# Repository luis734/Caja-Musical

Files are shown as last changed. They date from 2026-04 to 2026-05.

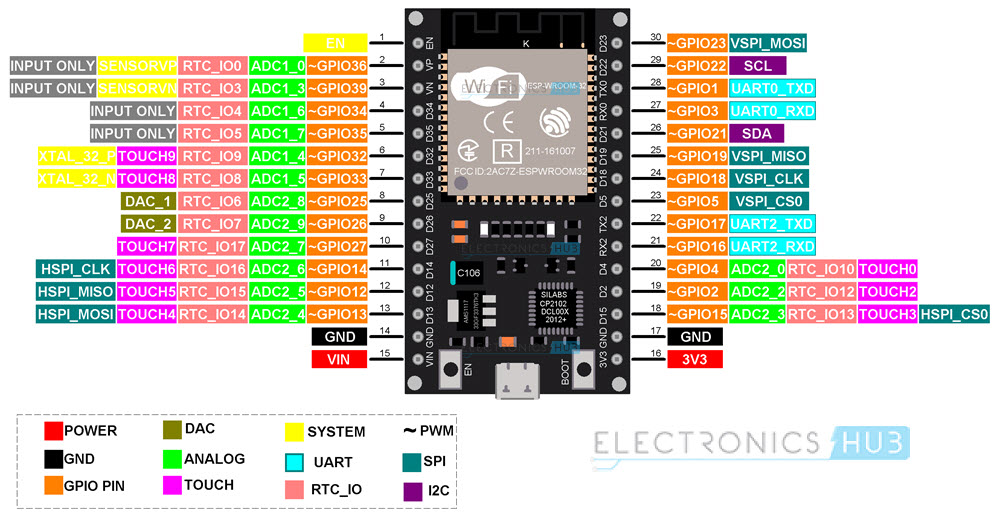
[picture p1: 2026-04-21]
docs/conexiones/ESP32-Pinout.jpg

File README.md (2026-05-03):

# 🎵 Caja Musical RFID — Tocadiscos Interactivo

Una caja musical tipo tocadiscos construida con **ESP8266 + RFID + DFPlayer Mini**, donde al acercar una tarjeta RFID al lector se reproduce automáticamente una canción almacenada en una MicroSD.

La idea principal es simular la experiencia de colocar un vinilo sobre un tocadiscos:

➡️ Acercas una tarjeta RFID  
➡️ Comienza a reproducirse la música  
➡️ Al retirar la tarjeta, la música se detiene

Actualmente el proyecto funciona sobre protoboard y está pensado como un proyecto personal realizado por gusto, con posibilidad de seguir creciendo hacia una versión física más elaborada con disco giratorio y mejor acabado visual.

---

# ✨ Características

- Reproducción automática de música mediante RFID
- Modo normal de uso (funcionamiento principal)
- Modo administrador para programar tarjetas
- Soporte para tarjetas **MIFARE Ultralight**
- Uso de **DFPlayer Mini + bocina 3W**
- LED RGB con efecto de respiración (opcional)
- Proyecto modular y fácil de expandir

> El LED RGB es únicamente decorativo y puede eliminarse fácilmente sin afectar el funcionamiento principal.

---

# ⏯️ Comportamiento en tiempo real

### Tarjeta presente

▶️ La música se reproduce continuamente

### Tarjeta retirada

⏹️ La música se detiene

---

# 🧩 Componentes Utilizados

- ESP32
- RC522 RFID Reader
- DFPlayer Mini
- Bocina de 3W
- LED RGB (opcional)
- MicroSD
- Tarjetas RFID MIFARE Ultralight
- Protoboard
- Cables Dupont

---

# 🔌 Diagramas de Conexión

Dentro de:

```text
/docs/conexiones
```

se incluyen:

- Diagramas de conexión individuales
- Diagrama completo del sistema
- Archivos fuente de Fritzing
- Listado de conexiones para una visualización mas sencilla

> [!NOTE]  
> Actualmente solo se realizó el diagrama de conexiones sobre protoboard.  
> Aun no se realizó diseño para PCB o placa de impresión.

---

# 📄 Documentación

Si necesitas saber como funciona algo mas especificamente puede revisar dentro de:

```text
/docs
```

En la raíz de esta carpeta encontrarás, información importante tipo:

- ¿Cómo funciona el Modo Admin? (`modo_admin.md`)
- ¿Cómo vincular las canciónes de la Micro SD y las RFID Tags? (`rfid_canciones.md`)
- ¿Cómo solucionar errores comúnes que te puedas encontrar? (`problemas_comunes.md`)

---

# 📁 Estructura  del Proyecto

```text
├── docs/
|   └── documentación_características.md
│   └── conexiones/
│       ├── diagramas individuales
│       ├── diagrama completo
│       ├── archivos Fritzing
│       └── listado de conexiones
│
├── src/
│   └── código fuente para ESP32
│
└── README.md
```

---

# 📌 Nota Final

Este proyecto nació como algo personal y experimental, pero está pensado para seguir creciendo hasta convertirse en una verdadera caja musical estilo tocadiscos interactivo.

Mas que solo reproducir música, la idea es crear una experiencia física y visual alrededor de ella.

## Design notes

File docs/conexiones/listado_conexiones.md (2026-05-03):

# 🔌 Conexiones del Proyecto

Este documento describe las conexiones físicas entre los módulos utilizados en la Caja Musical RFID.

El sistema principal está compuesto por:

- ESP32
- RC522 RFID Reader
- DFPlayer Mini
- Bocina de 3W
- LED RGB (opcional)

Actualmente todo el sistema está montado sobre **protoboard**, sin PCB personalizada.

---

# 📍 Protocolos de Comunicación Utilizados

| Módulo | Protocolo |
| --- | --- |
| RC522 | SPI |
| DFPlayer Mini | Serial UART (SoftwareSerial) |
| LED RGB | GPIO PWM |
| Bocina | Salida directa del DFPlayer  |

---

# 🧠 Consideraciones Importantes

## Niveles de Voltaje

El **RC522 trabaja a 3.3V**, por lo que debe conectarse correctamente para evitar daños.

El **DFPlayer Mini suele trabajar a 5V**, aunque puede funcionar con algunas configuraciones a menor voltaje.

## RX del DFPlayer

Se recomienda usar un pequeño divisor de voltaje en el pin **RX del DFPlayer Mini**, especialmente si se conecta desde una salida de 5V.

Esto ayuda a proteger el módulo.

## Alimentación

La bocina de 3W puede demandar más corriente de la esperada.

Si el audio presenta fallos o reinicios, se recomienda usar una fuente externa estable.

---

# 🔗 ESP32 ↔ RC522 (SPI)

> [!WARNING]
> No conectar el RC522 a 5V.

| ESP32 | RC522 |
| --- | --- |
| D5 | SDA / SS |
| D18 | SCK |
| D23 | MOSI |
| D19 | MISO |
| D22 | RST |
| 3.3V | 3.3V |
| GND | GND |

---

# 🎵 ESP32 ↔ DFPlayer Mini

| ESP32 | DFPlayer Mini |
| --- | --- |
| TX2 | RX |
| RX2 | TX |
| VIN | VCC |
| GND | GND |

> [!NOTE]
> Verifica los pines reales usados en tu código fuente, especialmente si cambias SoftwareSerial.

---

# 🔊 DFPlayer Mini ↔ Bocina 3W

| DFPlayer Mini | Bocina |
| --- | --- |
| SPK_1+ | Cable rojo |
| SPK_2- | Cable negro|

> [!NOTE]
> No conectar la bocina a GND.  
> Debe ir directamente entre SPK_1 y SPK_2.

---

# 🌈 ESP32↔ LED RGB (Opcional)

| ESP32 | LED RGB |
| --- | --- |
| D25 | R |
| D26 | G |
| D27 | B |
| GND | Cátodo común |

> [!NOTE]
> Debe haber una resistencia de entre 220 o 330 ohms entre el pin del ESP y cada pata del LED para evitar que se queme, para mas información revisa docs/conexiones/LedRGB.
> El LED RGB usa efecto de respiración decorativo y puede eliminarse fácilmente.

---

# 📋 Resumen de Pines Utilizados

| Pin ESP8266 | Uso |
| --- | --- |
| D17 (TX2) | DFPlayer RX |
| D16 (RX2) | DFPlayer TX |
| D22 | RC522 RST |
| D18 | RC522 SCK |
| D19 | RC522 MISO  |
| D23 | RC522 MOSI  |
| D5 | RC522 SDA |
| GPIO extra  | LED RGB |

---

# 🔄 Si usas otra placa (Arduino UNO / ESP8266 / etc.)

Debes revisar principalmente:

- Pines SPI
- Pines Serial
- Voltajes compatibles
- Capacidad de corriente
- Compatibilidad con SoftwareSerial

Puede requerir más cuidado con niveles de voltaje y memoria disponible.

---

# 📁 Diagramas Visuales

En esta misma carpeta encontrarás:

- Diagramas individuales
- Diagrama completo del sistema
- Archivos fuente de Fritzing

Estos diagramas sirven como referencia visual complementaria a esta tabla.

---

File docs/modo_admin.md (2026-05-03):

# ⚙️ Modo Administrador

Este es un modo especial para progrtamar nuevas tarjetas RFID.

## ¿Cómo entrara?

Hay una tarjeta predefinida como Tarjeta Master, su UID está hardcodeado en el código fuente en la variable global:

```text
adminUID
```

### Al acercar esta tarjeta:
➡️ El sistema entra en Modo Admin
### Al acercarla de nuevo:
⬅️ El sistema sale del Modo Admin

---

# ¿Cómo programar una tarjeta?

Estando en Modo Admin

### Paso 1

Acerca una tarjeta RFID MIFARE Ultralight (y mantenla sobre el lector)

### Paso 2

Desde el Monitor Serial, envía el número de canción desdeado
Ejemplo:

```text
12
```

### Paso 3

Ese valor se escribe en la memoria de la tarjeta RFID, ya puedes retirar la tarjeta del lector

Ahora al acercar esta tarjeta al lector reproducirá:

```text
012.mp3
```

> [!NOTE]
> Las Tags RFID solo reproducen la canción en modo normal.
> En modo admin siempre se intentaran reprogramar.

### Programar múltiples tarjetas

Puedes seguir acercando nuevas tarjetas y asignarles números de canciones una por una.

## 💡 Como hacer tu propia Tarjeta MASTER

Tienes que identificar cual es el UID de la Tarjeta que designaras como MASTER, desde el IDE de Arduino en la librería `MFRC522.h` puedes revisar ejemplos simples para:

- Leer los datos de la tarjeta
- Reprogramar UID de alguna tarjeta
- Entre otros ejemplos muy utiles.

De esta forma puedes ajustarte al UID definida o cambiarla por la que necesites.

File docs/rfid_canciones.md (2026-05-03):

# 💿 Funcionamiento: RFID ↔ Canciones

Este documento explica cómo se relacionan las **tarjetas RFID** con las canciones reproducidas en la **MicroSD** mediante el DFPlayer Mini.

La lógica del sistema es simple:

> 📀 Cada tarjeta RFID representa una canción

---

# 🧠 Idea General

1. Una tarjeta RFID guarda un número
2. El ESP8266 lee ese número
3. Envía ese número al DFPlayer Mini
4. El DFPlayer reproduce la canción correspondiente en la MicroSD

---

# 📡 Estructura de las Tarjetas RFID (MIFARE Ultralight)

Las tarjetas utilizadas son del tipo **MIFARE Ultralight**, que tienen una memoria organizada de la siguiente forma:

- 16 páginas (pages)
- Cada página tiene 4 bytes

## 📋 Distribución básica

| Página | Contenido |
|---|---|
| 0 - 3 | Información del fabricante (incluye UID) |
| 4 en adelante | Memoria libre para usuario |

---

## 🔑 UID de la tarjeta

Las primeras páginas contienen el identificador único (UID), que:

- Es de solo lectura
- Identifica cada tarjeta de forma única
- Se usa en el proyecto para definir la **tarjeta admin (master)**

---

# ✍️ Dónde se guarda la canción

El sistema escribe el número de canción en:

### 👉 Página 4 (quinta página)
Esto se hace en el **modo administrador**.

---

# ⚙️ ¿Qué se guarda exactamente?

Se guarda un número en formato texto, por ejemplo:

```text
5
```
ó
```text
12
```

Este número representa la canción que se va a reproducir.

---

# 🔄 Flujo completo

## 🔹Paso 1: Lectura de tarjeta

El RC522 detecta una tarjeta y el ESP32:
- Lee la página 4
- Obtiene el número almacenado

## 🔹Paso 2: Envío al DFPlayer

- El ESP32 envía ese número al DFPlayer Mini meidante
UART (Serial)

## 🔹Paso 3: Reproducción

- El DFPlayer Mini busca en la MicroSD el archivo correspondiente a ese número.

---

# 💾 Formato de las canciones en la MicroSD

Las canciones deben nombrarse con un formato especifico:

## 👉 3 dígitos con ceros a la izquierda

## 📀 Ejemplos
| Número en RFID | Archivo en MicroSD |
|---|---|
| 1 | 001.mp3 |
| 2 | 002.mp3 |
| 3 | 003.mp3 |
| 10 | 010.mp3 |
| 12 | 012.mp3 |

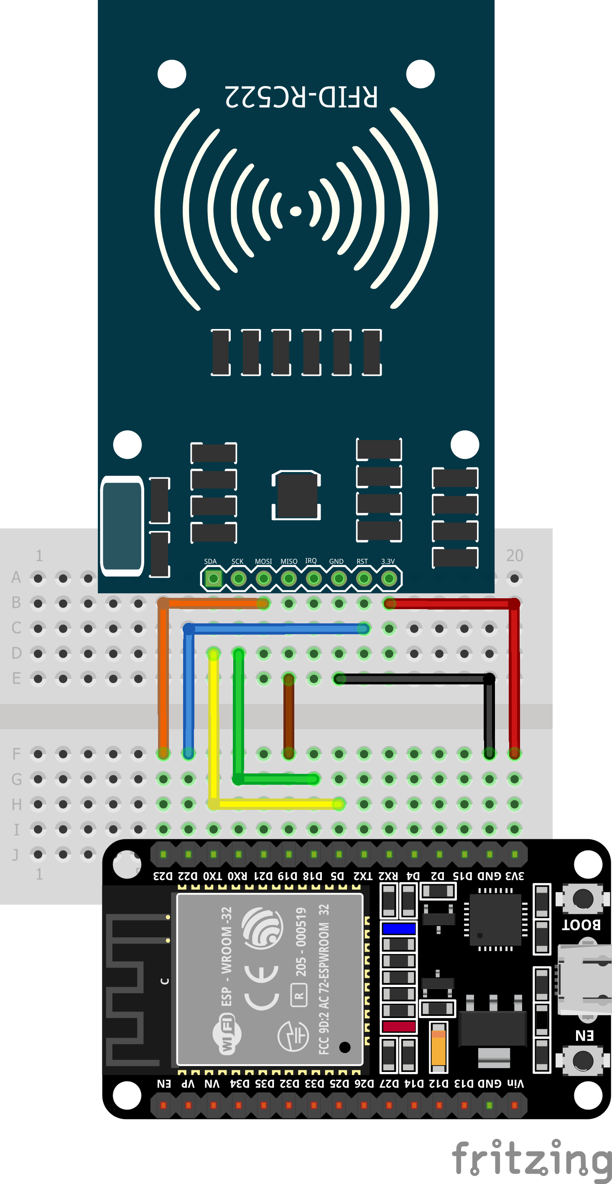
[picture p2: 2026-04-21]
docs/conexiones/RFID/RFID_v2.png

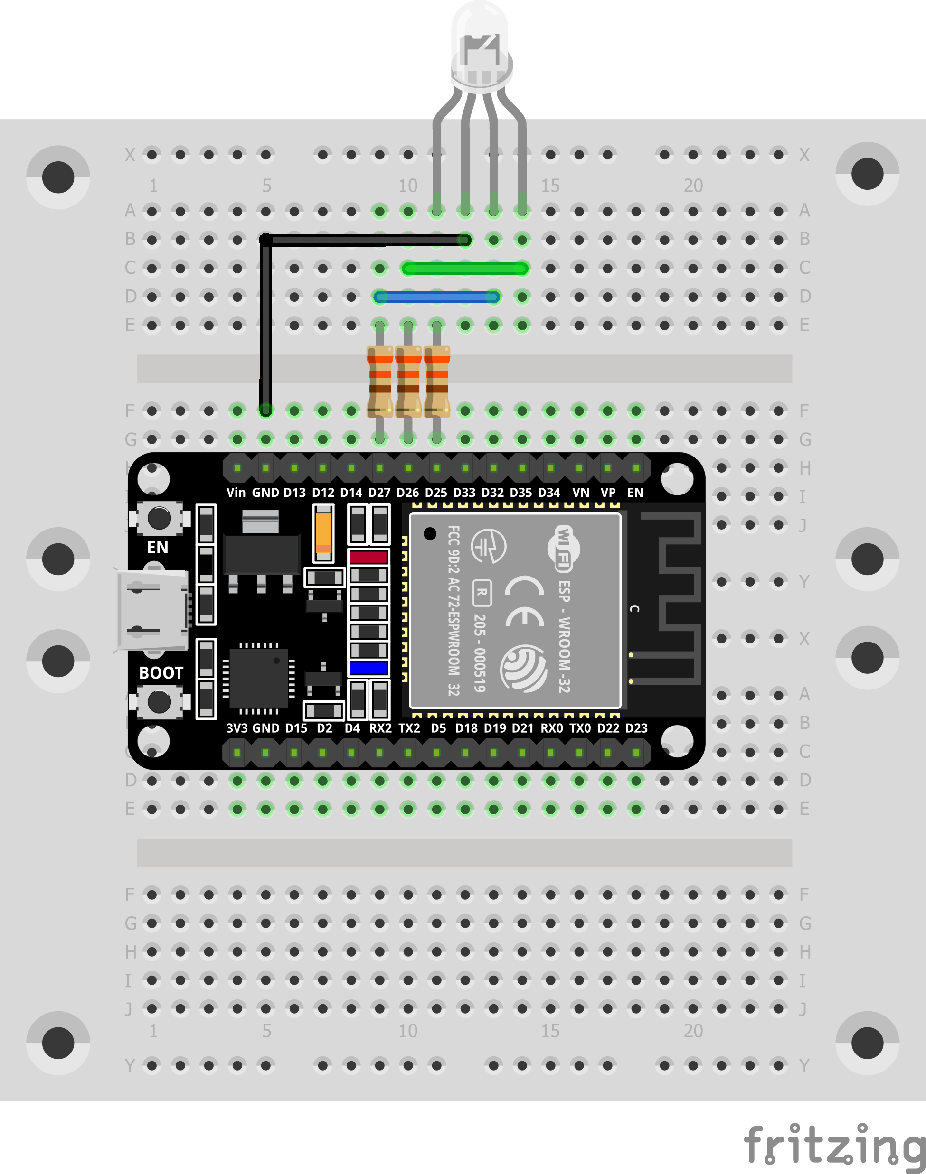
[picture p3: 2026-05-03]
docs/conexiones/RGB/RGB.png

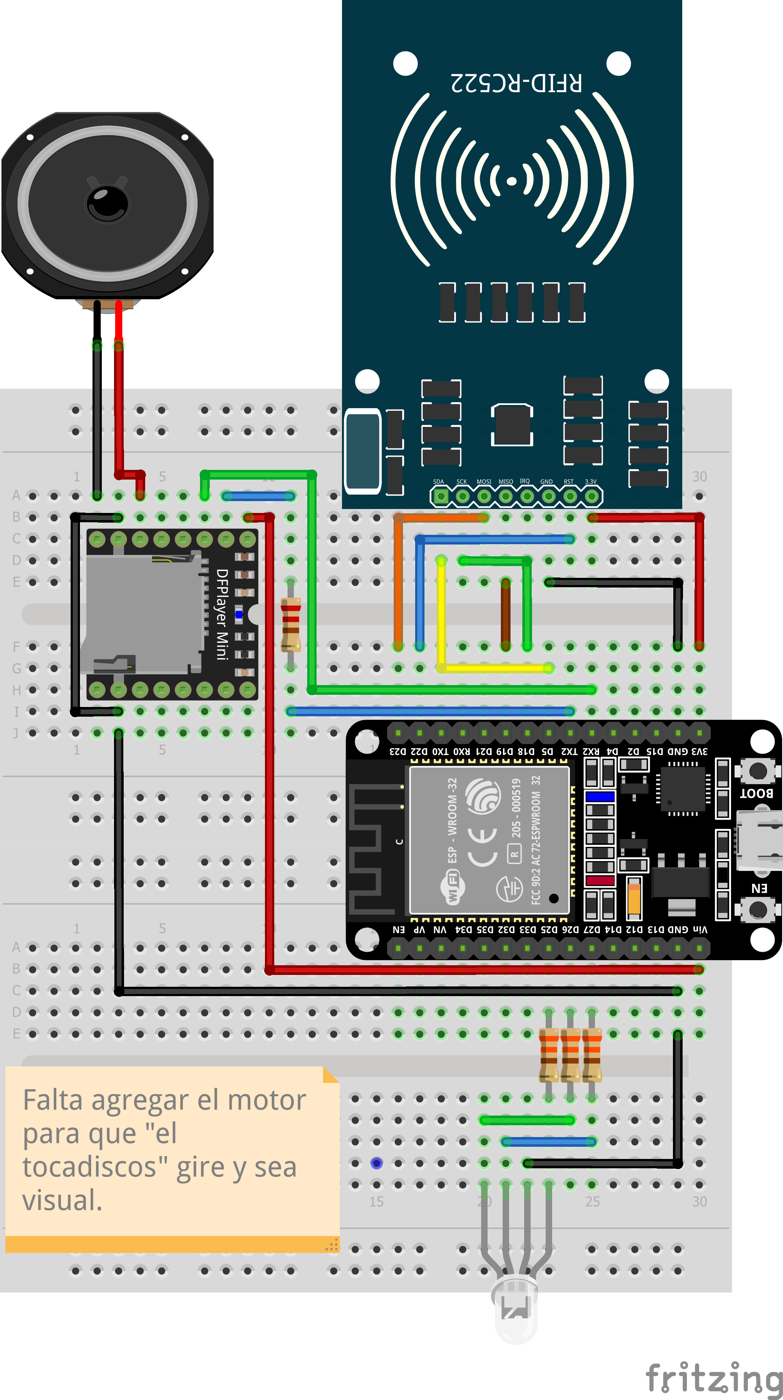
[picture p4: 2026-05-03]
docs/conexiones/Completo/Completo.png

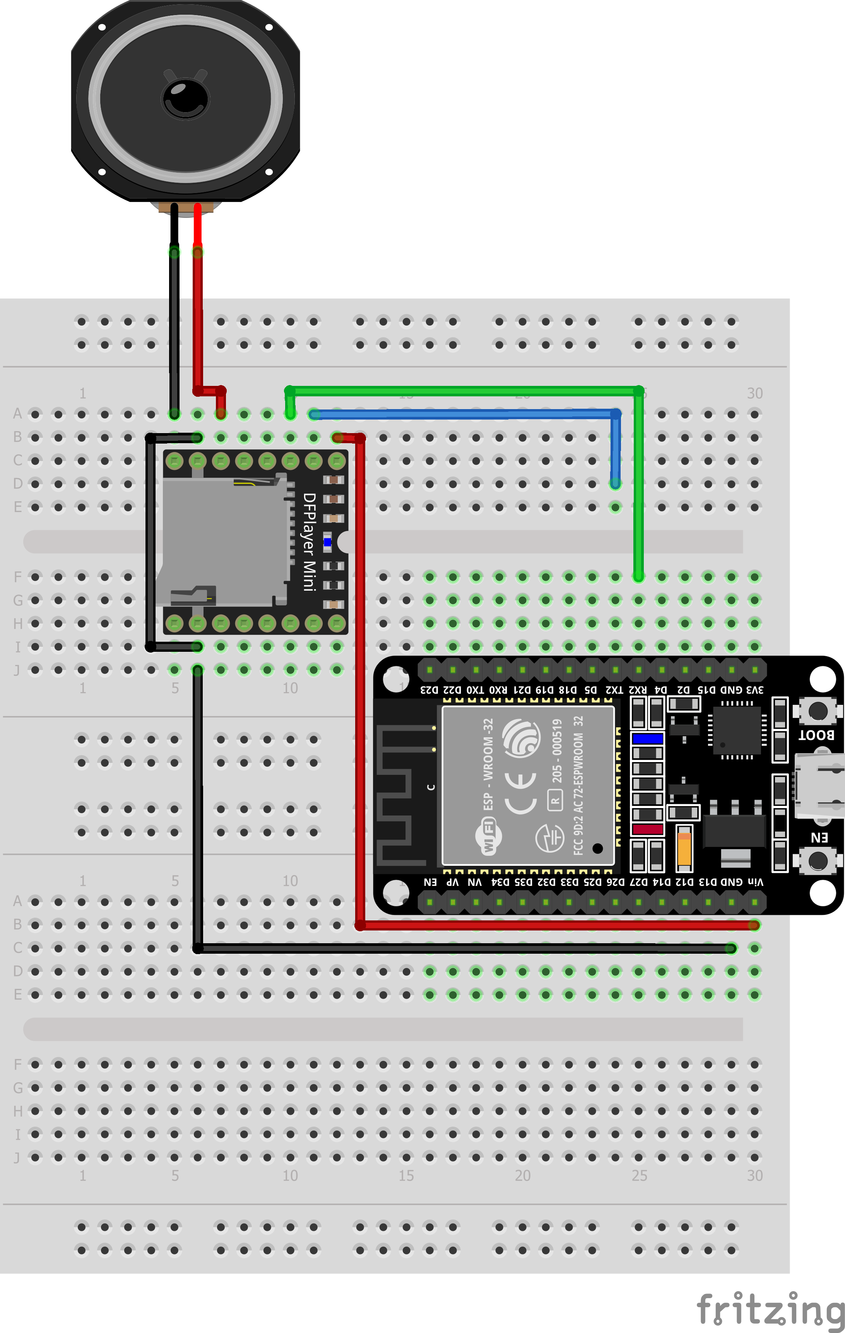
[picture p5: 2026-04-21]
docs/conexiones/DFPlayerMini/DFPlayer.png

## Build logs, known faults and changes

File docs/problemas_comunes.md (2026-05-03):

# 🛠️ Problemas Comunes y Soluciones

Este documento recopila los problemas reales encontrados durante el desarrollo de la **Caja Musical RFID** y cómo fueron solucionados.

La intención es ayudar a otros a evitar errores comunes y acelerar el proceso de implementación.

---

# 📌 Cómo usar este documento

Cada problema incluye:

- **Síntomas** → Qué ocurre
- **Causa** → Por qué ocurre
- **Solución** → Cómo corregirlo

---

# 🔌 Problemas de Hardware

## ❌ El ESP se reinicia constantemente

**Síntomas:**

- Envia un log indicando reinicio forzado
- Imprime símbolos raros de forma constante

**Causa:**

- Se usaban pines incorrectos para comunicación (RX/TX mal conectados)
- Interferencia con el Serial de la placa y el ESP entraba en reset loop/watchdog reset

**Solución:**

- Cambia el monitor serial a 74880 baudios para ver el mensaje de error
- Revisa que tu placa no requiera esos pines para arranque o que no interfiera con la comunicación serial
- Si usas SoftwareSerial cambialo a otros pines

---

## ❌ DFPlayer no reproduce sonido

**Síntomas:**

- No se escucha nada
- El módulo enciende pero no hay audio

**Causa:**

- Bocina mal conectada
- Alimentación insuficiente

**Solución:**

- Conectar la bocina directamente entre:
  - `SPK_1` ↔ bocina
  - `SPK_2` ↔ bocina
- No conectar a GND
- Verificar que la fuente entregue suficiente corriente

---

## ❌ Audio distorsionado o muy bajo 🔥

**Síntomas:**

- Sonido con ruido
- Volumen bajo

**Causa:**

- Fuente inestable
- Bocina no adecuada
- Canciones con distintos niveles de volumen

**Solución:**

- Usar fuente externa estable
- Verificar impedancia de la bocina (3W compatible)
- Aplica un filtro Loudness Normalization para cambiar el nivel del audio

---

## ❌ RC522 no detecta tarjetas

**Síntomas:**

- No aparece nada en el monitor serial

**Causa:**

- Conexión incorrecta
- Voltaje incorrecto

**Solución:**

- Verificar conexiones SPI
- ⚠️ Asegurar uso de **3.3V (🚧 NO 5V)**

---

## ❌ Reinicios del ESP32 al reproducir 🔥

**Síntomas:**

- El ESP se reinicia al iniciar audio

**Causa:**

- Consumo de corriente elevado (DFPlayer + bocina)
- Error de comunicación

**Solución:**

- Usar fuente externa para DFPlayer
- Compartir GND entre todos los módulos
- Si usas puertos que la placa necesita para inicializar, se reinicia constantemente.
- Verifica que no estes usando el protocolo de comunicación correcto

---

# 📡 Problemas de Comunicación

## ❌ DFPlayer no responde a comandos 🔥

**Síntomas:**

- El código corre pero no reproduce nada

**Causa:**

- Confusión en protocolo de comunicación

**Importante:**

> El DFPlayer **NO usa SPI**, usa **UART (Serial)**

**Solución:**

- Usar `SoftwareSerial` o UART real
- Conectar correctamente:
  - TX ↔ RX
  - RX ↔ TX

---

## ❌ Comunicación inestable con DFPlayer

**Síntomas:**

- A veces funciona, a veces no

**Causa:**

- Ruido eléctrico o mala conexión

**Solución:**

- Revisar cables
- Evitar cables largos
- (Opcional) usar divisor de voltaje en RX

---

# 🧠 Problemas de Lógica / Código

## ❌ La canción se reproduce y se detiene inmediatamente 🔥

**Síntomas:**

- La canción inicia pero se corta al instante

**Causa:**

- El RFID se lee constantemente sin control
- Se dispara múltiples veces la reproducción

**Solución:**

- Detectar estado de presencia de tarjeta
- Evitar reiniciar la canción si ya está activa

---

# 💾 Problemas con la MicroSD

## ❌ No reproduce archivos 🔥

**Síntomas:**

- DFPlayer responde pero no reproduce

**Causa:**

- Nombres incorrectos de archivos

**Solución:**

- Usar formato obligatorio:

```text
001.mp3
002.mp3
003.mp3
```
---

# 📘 Lecciones Aprendidas

- El DFPlayer Mini usa UART, no SPI
- El RFID requiere control de estado, no solo lectura
- La MicroSD es crítica (nombres, formato, orden)
- La alimentación es clave para estabilidad
- Evitar múltiples tarjetas mejora mucho la confiabilidad

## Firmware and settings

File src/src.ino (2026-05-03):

#include <SPI.h>
#include <MFRC522.h>
#include <HardwareSerial.h>
#include <DFRobotDFPlayerMini.h>

// ---- Variables globales ----
// RFID
  // En caso de quere cambiar de pines, el numero representa el GPIO no el numero Dn de la placa.
#define RST_PIN 22 // D22
#define SS_PIN 5  // D5
MFRC522 rfid(SS_PIN, RST_PIN);

// DFPlayer
HardwareSerial dfSerial(2); // UART2
DFRobotDFPlayerMini dfPlayer;
unsigned long ultimoReplay = 0;
int trackActual = -1;

// Manejo de TAG presente
String uidActual = "";
bool tarjetaPresente = false;

// Manejo de TAG retirada
unsigned long ultimoPing = 0;
unsigned long ultimaRespuesta = 0;

const unsigned long intervaloPing = 100;
const unsigned long timeoutRFID = 500;

// Modo ADMIN
bool modoAdmin = false;
String adminUID = "B4CEEF06";
byte adminPage = 5;

// Manejo de RGB (Catodo comun)
#define LED_R 25
#define LED_G 26
#define LED_B 27

// ---- Prototipos de funciones ----
void detectarNuevaTarjeta();
void verificarPresenciaRFID();
String obtenerUID();
void reproducirCancion(String uidActual);
void breathingEffect();
void apagarLED();
void verificarTerminoCancion();
// MODO ADMIN
void manejarModoAdmin();
bool escribirTrackEnTarjeta(int track);
int leerTrackDesdeTarjeta();

void setup() {
  Serial.begin(115200);

  // RFID
  SPI.begin();
  rfid.PCD_Init();

  // DFPlayer
  dfSerial.begin(9600, SERIAL_8N1, 16, 17); // RX2, TX2
  delay(3000);

  if (dfPlayer.begin(dfSerial)) {
    Serial.println("DFPlayer OK");
  } else {
    Serial.println("Error DFPlayer");
  }

  // RGB
  ledcSetup(0, 5000, 8);
  ledcAttachPin(LED_R, 0);

  ledcSetup(1, 5000, 8);
  ledcAttachPin(LED_G, 1);

  ledcSetup(2, 5000, 8);
  ledcAttachPin(LED_B, 2);
}

void loop() {
  if (modoAdmin) {
    manejarModoAdmin();
    return;
  }

  detectarNuevaTarjeta();

  if (tarjetaPresente){
    verificarPresenciaRFID();

    // Detectamos si la canción termino para repetirla
    verificarTerminoCancion();

    // * Elimina esta linea y el else si no quieres agregar el led rgb.
    breathingEffect();
  } else {
    apagarLED();
  }
}

void detectarNuevaTarjeta() {
  if (!rfid.PICC_IsNewCardPresent()) return;

  if (!rfid.PICC_ReadCardSerial()) return;

  String nuevoUID = obtenerUID();

  if (nuevoUID == adminUID) {

    modoAdmin = !modoAdmin;

    if (modoAdmin) {
      Serial.println("=== MODO ADMIN ACTIVADO ===");
      Serial.println("Acerca una tarjeta para programarla");
    } else {
      Serial.println("=== MODO ADMIN DESACTIVADO ===");
    }

    rfid.PICC_HaltA();
    rfid.PCD_StopCrypto1();

    delay(1000); // evita doble lectura accidental
    return;
  }

  if (nuevoUID != uidActual) {
    uidActual = nuevoUID;
    tarjetaPresente = true;

    reproducirCancion(uidActual);
  }

  ultimaRespuesta = millis();

  rfid.PICC_HaltA();
  rfid.PCD_StopCrypto1();
}

void verificarPresenciaRFID() {
  if (millis() - ultimoPing < intervaloPing) return;

  ultimoPing = millis();

  byte bufferATQA[2];
  byte bufferSize = sizeof(bufferATQA);

  MFRC522::StatusCode status = rfid.PICC_WakeupA(bufferATQA, &bufferSize);

  if (status == MFRC522::STATUS_OK) {
    ultimaRespuesta = millis();
  }

  if (millis() - ultimaRespuesta > timeoutRFID) {
    // Detener la canción actual
    dfPlayer.stop();

    tarjetaPresente = false;
    uidActual = "";
    trackActual = -1;
  }
}

String obtenerUID() {
  String uid = "";

  for (byte i = 0; i < rfid.uid.size; i++) {
    if (rfid.uid.uidByte[i] < 0x10) {
      uid += "0"; // Si el dato es entre 0 y 9 agregamos un 0 para mantener el formato correcto.
    }

    uid += String(rfid.uid.uidByte[i], HEX);
  }

  uid.toUpperCase();
  return uid;
}

void reproducirCancion(String uidActual) {
//   Verificamos si ya había una canción guardada o hay que leer una nueva
  if (trackActual == -1) {
    trackActual = leerTrackDesdeTarjeta();
  }

  if (trackActual != -1) {
    Serial.print("Reproduciendo track: ");
    Serial.println(trackActual);

    dfPlayer.volume(15);
    dfPlayer.play(trackActual);
    return;
  }

  Serial.println("No se encontró track en la tarjeta");
}

void breathingEffect() {

  static int brillo = 0;
  static int direccionBrillo = 5;

  static int colorIndex = 0;

  brillo += direccionBrillo;

  if (brillo >= 255 || brillo <= 0) {
    direccionBrillo = -direccionBrillo;

    // Cuando completa una respiración,
    // cambia al siguiente color
    if (brillo <= 0) {
      colorIndex++;
      if (colorIndex > 5) {
        colorIndex = 0;
      }
    }
  }

  int r = 0;
  int g = 0;
  int b = 0;

  switch (colorIndex) {

    case 0: // rojo
      r = brillo;
      break;

    case 1: // morado
      r = brillo;
      b = brillo;
      break;

    case 2: // azul
      b = brillo;
      break;

    case 3: // cyan
      g = brillo;
      b = brillo;
      break;

    case 4: // verde
      g = brillo;
      break;

    case 5: // amarillo
      r = brillo;
      g = brillo;
      break;
  }

  ledcWrite(0, r);
  ledcWrite(1, g);
  ledcWrite(2, b);

  delay(25);
}

void apagarLED() {
  ledcWrite(0, 0);
  ledcWrite(1, 0);
  ledcWrite(2, 0);
}

void verificarTerminoCancion() {
  if (!dfPlayer.available()) return;

  uint8_t type = dfPlayer.readType();
  uint16_t value = dfPlayer.read();

  if (type != DFPlayerPlayFinished) return;
  // Si la canción ya termino, como la tarjeta sigue presente repetimos la canción

  Serial.print("Canción terminada: ");
  Serial.println(value);

  // Definimos tiempo de debounce para evitar multiples reinicios
  if (millis() - ultimoReplay < 200) return; 
  
  delay(100);

  reproducirCancion(uidActual);

  ultimoReplay = millis();
}

// * ==== FUNCIONES MODO ADMIN ====
void manejarModoAdmin() {

  if (!rfid.PICC_IsNewCardPresent()) return;
  if (!rfid.PICC_ReadCardSerial()) return;

  String nuevoUID = obtenerUID();

  // Si vuelves a acercar la tarjeta ADMIN → salir
  if (nuevoUID == adminUID) {
    modoAdmin = false;

    Serial.println("=== MODO ADMIN DESACTIVADO ===");

    rfid.PICC_HaltA();
    rfid.PCD_StopCrypto1();
    delay(1000);
    return;
  }

  Serial.println("--------------------------------");
  Serial.print("Tarjeta detectada: ");
  Serial.println(nuevoUID);

  Serial.println("Ingresa numero de track por Serial Monitor:");

  // Esperar entrada por serial
  while (!Serial.available()) {
    delay(10);
  }

  int track = Serial.parseInt();

  if (track <= 0) {
    Serial.println("Track invalido");

    rfid.PICC_HaltA();
    rfid.PCD_StopCrypto1();
    return;
  }

  if (escribirTrackEnTarjeta(track)) {
    Serial.print("Track guardado correctamente: ");
    Serial.println(track);
  } else {
    Serial.println("Error escribiendo track");
  }

  rfid.PICC_HaltA();
  rfid.PCD_StopCrypto1();

  Serial.println("Acerca otra tarjeta o la ADMIN para salir");
}

bool escribirTrackEnTarjeta(int track) {
  MFRC522::StatusCode status;

  byte dataPage[4] = {0};

  String trackStr = String(track);

  for (int i = 0; i < trackStr.length() && i < 4; i++) {
    dataPage[i] = trackStr[i];
  }

  status = rfid.MIFARE_Ultralight_Write(
    adminPage,
    dataPage,
    4
  );

  if (status != MFRC522::STATUS_OK) {
    Serial.println("Error escribiendo page Ultralighy");
    return false;
  }

  Serial.println("Track escrito correctamente");

  return true;
}

int leerTrackDesdeTarjeta() {
  MFRC522::StatusCode status;

  byte buffer[18];
  byte size = sizeof(buffer);

  status = rfid.MIFARE_Read(
    adminPage,
    buffer,
    &size
  );

  if (status != MFRC522::STATUS_OK) {
    Serial.println("Error leyendo track");
    return -1;
  }

  // Solo usamos los primeros 4 bytes
  String trackStr = "";

  for (int i = 0; i < 4; i++) {
    if (buffer[i] != 0 && isDigit(buffer[i])) {
      trackStr += (char)buffer[i];
    }
  }

  int track = trackStr.toInt();

  Serial.print("Track leido: ");
  Serial.println(track);

  return track;
}

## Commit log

2026-04-18 Proyecto Caja Musical, codigo inicial con lector de RFID
2026-04-18 Se agrego el README.md con una descripcion breve del proyecto y la estructura.
2026-04-21 Se documentaron conexiones, se integraron DFPlayer y RC522 en conjunto
    [DFPlayer.fzz, RFID.fzz]
2026-05-02 (Update) Se ajusto la estructura de código base para detectar cuando una RFID esta sobre el lector (reproducir cancion) y detectar cuando se quita (detener cancion).
    [Completo.fzz]
2026-05-02 (Update) Se cambio el modo para identificar el numero de canción, y se agrego el modo administrador.
    - El modo admin se maneja para programar nuevos RFIDs.
    - Se eliminó el mapeo de canciones a UID especificos.
    - Se agrego la funcion para leer el numero de canción desde el TAG.
    - Se agrego la funcion de admin para escribir el numero de canción al TAG.
2026-05-02 (FEAT) Se agregó un led RGB (catodo comun), con efecto de respiración.
    - Se agrego la función para el efecto de respiración.
    - Se agrego la logica en el loop para manejar el LED (ON/OFF).
2026-05-03 (UPDATE)Actualización del README.md y se documentaron las conexiones.
    - Se creo el documento lista_conexiones para listar los pines usados entre cada componente y el ESP.
    - Se detallo los datos importantes de las conexiones y consideracions para otras placas.
2026-05-03 (FEAT) Se agrego el diagrama de conexiones individual y al diagrama completo para la adición del led RGB.
    - Se crearon los archivos individuales de conexion para el led RGB.
    - Se actualizo el diagrama completo para considerar el led RGB.
    [Completo.fzz, RGB.fzz]
2026-05-03 (UPDATE) Actualización del README.md con nuevas secciones y detalles sobre el comportamiento en tiempo real.
    - Se agregó información sobre el comportamiento de la música al retirar o colocar la tarjeta.
    - Se actualizó la lista de componentes para reflejar el uso del ESP32.
    - Se incluyeron diagramas de conexión y documentación adicional en la carpeta /docs.
    - Se mejoró la estructura del proyecto y se añadió una nota final sobre la visión del proyecto.
2026-05-03 Update modo_admin.md
    Corrección error en la nota.
2026-05-03 (FEAT) Implementación de la lógica para repetir canciones al finalizar.
    - Se agregó la función `verificarTerminoCancion` para detectar el final de la reproducción.
    - Se modificó `reproducirCancion` para manejar el seguimiento del track actual.
    - Se implementó un debounce para evitar múltiples reinicios de la canción.
